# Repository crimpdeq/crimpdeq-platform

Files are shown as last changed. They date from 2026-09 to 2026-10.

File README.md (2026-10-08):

# Crimpdeq Platform

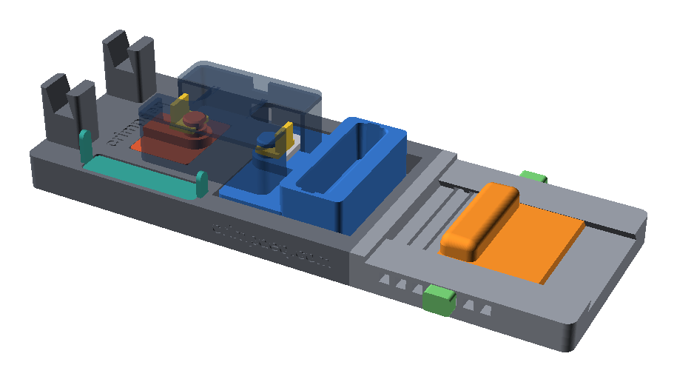
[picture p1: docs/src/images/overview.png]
Assembled platform


A parametric OpenSCAD platform that turns the [Crimpdeq](https://github.com/crimpdeq)
portable force sensor into an isometric finger dynamometer, printed
entirely in plastic with no hardware to buy.

## Specifications

- **Edge depths:** 25, 20, 15 and 10 mm, set with two stackable stoppers (5
  and 10 mm).
- **Palm rest:** 25–85 mm from the outside of the finger lip to the palm face,
  seven positions in 10 mm steps, with the heel level with the fingertips on
  the 20 and 25 mm edges.
- **Phone slot:** phones up to about 13 mm thick in their case, portrait or
  landscape, leaned back 15°.
- **Size:** 349 × 122 mm base (138 mm wide with the keys fitted), 60 mm tall
  at the phone stand.
- **Printing:** no supports and no hardware; the base splits into two halves
  for a 256 mm bed; about 640 g of PETG.
- **Compatibility:** [crimpdeq-case](https://github.com/crimpdeq/crimpdeq-case)
  v2.0.0 and earlier.

## Documentation

The [book](https://platform.crimpdeq.com) ([source](docs/src/SUMMARY.md)) covers the design requirements, a
step-by-step guide to printing and assembling the parts on a 256 mm printer,
and the development workflow. Build it locally with [mdBook](https://rust-lang.github.io/mdBook/):

```bash
mdbook serve docs
```

## Quick start

Ready-to-print STL files and a Bambu Studio project with the plates laid out
are attached to each
[release](https://github.com/crimpdeq/crimpdeq-platform/releases). To preview
the model or export the parts yourself:

```bash
openscad dynamometer_assembly.scad
bash export-parts.sh
```

Validate the geometry after any change to the model:

```bash
CHECK_JOBS=4 OPENSCAD_RENDER_FN=24 bash check-collisions.sh
```

## Safety

Never load the platform above its 49 kg rating, and pull only with both clips
and both keys fitted. Printed parts can fail: inspect them before each session
and stop using any part that cracks or deforms.

## License

This repository is source-available under the
[Crimpdeq Non-Commercial Hardware License](LICENSE). You may study, modify,
and build the design for personal, educational, and research use, and share
modified versions non-commercially. Commercial manufacture or sale of printed
parts, kits, or assembled devices requires prior written permission.
The bundled Inter font in `fonts/` is under its own
[SIL Open Font License](fonts/Inter-LICENSE.txt).

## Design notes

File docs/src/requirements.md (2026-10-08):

# Requirements

These are the requirements the design must keep. A change to the model that
breaks one is a design change, not a tweak, and this page changes with it.
The structural assertions and collision checks screen many of them; none of
them replaces testing printed parts.

## Load rating

- The platform is rated for 49 kg (about 481 N). The Crimpdeq itself is rated
  to 1500 N (about 150 kg); the printed lugs set the lower limit.
- The printed structure is sized with a 2.0 structural design factor, but the
  platform is never loaded above its 49 kg rating.

## Printing

- Every part is 3D-printed. There are no bolts, pins, inserts or other
  purchased hardware.
- Every part prints without supports.
- Each base half fits within the 240 mm printable length of a 256 mm bed
  (Bambu Lab A1). The halves join with vertical dovetails whose joint faces
  are in compression under load.

## Case and load path

- The platform holds the crimpdeq-case `v2.0.0` enclosure and every
  earlier release.
- The case lies flat, lid up, and floats at least 1 mm above the deck and
  clear of every printed part. Its shell, lid and screws never carry load.
- Hand force passes through printed round lugs in the Ø15 mm ring bores
  of both load-cell eyes: the anchor block's lug and the grip's lug. Each
  stands on a tongue rising through the case's eye U-slot, at least 1 mm
  from the case and its lid battery walls.
- The lugs are solid. The anchor block and grip print upright, so the lug and
  tongue roots are screened across the layers.
- Two snap-on eye clips hold the load cell down under the lug heads. Each
  fits by dropping into its U-slot and sliding onto the lug neck, with finger
  room beside the grip-side fin.
- The clips carry the grip's tilt but not the pull; the clip ring and lug
  neck are screened for that tilt.
- The switch and USB port stay reachable from the open +Y side of the base.

## Finger pocket and stoppers

- The four-finger hangboard pocket is exactly 25 mm deep, with an opening at
  least 80 mm wide, a 6 mm back wall and an 8 mm loading lip. Its +Z opening
  stays clear.
- The mid-depth of every edge is within 5 mm of the load-cell plane. The
  current model is at most 4 mm off, on the 10 mm edge.
- Two stackable drop-in stoppers, 5 and 10 mm thick, give 20, 15 and 10 mm
  edges. The closed pocket walls locate them.
- Their pull tabs run in slots in the pocket end walls and stand proud of the
  grip top, leaving the whole top of each stopper free for the fingers.
- The stoppers are stored in a well in the deck beside the case.
- Grip-guide ledges run under the grip's side walls with a 0.8–1.2 mm Z gap
  and free X travel, so they catch tilt without carrying measured load.

## Palm rest

- The heel deck (the rest's plate and the rear deck beside it) lies between
  the fingertips on the 20 and 25 mm edges (Z = −10 mm), so the heel and the
  fingers pull in line. The palm bolster rises 10–14 mm above it.
- Nothing but the bolster stands above the heel deck around the hand.
- The rest has seven positively locked positions, for hand openings of 25 to
  85 mm.
- The rest slides in a dovetail channel sunk into the rear base half, which
  carries the whole heel plate at every position. Two printed index keys,
  pushed in under the deck from the sides of the base, lock it. Adjustment
  needs no tools.
- Either index key alone is screened for the entire design force, and both
  travel extremes are checked after every geometry change.

## Phone stand

- A tilted phone slot runs across a two-cheek stand at the far (−X) end of
  the base. A narrow phone rests on both cheeks.
- The slot floor is at Z = 15 mm, so the case hides the phone only from
  viewpoints less than 20° above the table.
- The stand leaves finger room by the stopper well, is outside the load path,
  and is clear of the hand at every rest position.

## Clearances

- The base, anchor block, grip, clips, rest, keys, phone and case are
  collision-free except at explicitly modelled contact surfaces.

## Structural screening

`dynamometer_dimensions.scad` fails with an assertion when a parameter change
takes any of these checks past its limit. Values are at the 961 N design
target: the 481 N rating times the 2.0 design factor.

| Check | Stress | Limit |
|---|---|---|
| Eye bearing on each lug (14.3 mm × 4 mm) | 16.8 MPa | 20 MPa, lug bearing |
| Lug root bending across the layers, eye force at the load-cell mid-plane | 6.7 MPa | 12 MPa |
| Lug root shear across the layers | 5.98 MPa | 6 MPa |
| Tongue root at the deck, bending across the layers | 3.1 MPa | 12 MPa |
| Anchor block bearing on its pocket | 1.1 MPa | 12 MPa, bearing |
| Clip on the flat ring under the lug head, largest finger-pull tilt | 11.1 MPa | 12 MPa, bearing |
| Lug neck pulled by the clip, across the layers | 4.4 MPa | 12 MPa |
| Finger lip bending over the full 25 mm edge | 18.0 MPa | 30 MPa, bending |
| Grip side and back walls in tension | 1.2 MPa | 12 MPa |
| Either index key alone, in shear at the channel floor | 4.3 MPa | 12 MPa |
| Key bearing in the rest's groove / the floor groove | 10.4 / 7.4 MPa | 12 MPa, bearing |
| Rib between neighbouring floor grooves, in shear | 7.0 MPa | 12 MPa |
| Palm bolster root, across the layers | 1.1 MPa | 12 MPa |
| Channel lips holding the rest down | 0.8 MPa | 6 MPa |

The clip check takes the 10 mm edge's 4 mm offset, reacted between the clip
and the tongue seat 10 mm from the eye centre. The base joint is in
compression and is not screened; the stoppers, grip guides, stopper well and
phone stand are outside the load path.

The printed-material limits (`allowable_printed_*` and
`allowable_lug_bearing_mpa`) are assumptions that need coupon tests. The
calculations leave out the 3D stress field, notches, one-finger loading,
print defects, creep, fatigue and temperature, and they are not FEA or proof
tests. The design factor is not a demonstrated safety factor and never
permits loading the platform above 49 kg.

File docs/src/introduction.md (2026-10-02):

# Crimpdeq Platform

Assembled platform

Crimpdeq Platform is a parametric OpenSCAD design that turns the
[Crimpdeq](https://github.com/crimpdeq) force sensor into an isometric finger
dynamometer.

Every part is 3D-printed. There are no bolts, pins, inserts or other
hardware to buy.

## How this book is organised

[Requirements](requirements.md) lists what the design must keep.
[Build](build/index.md) explains how to print the parts and assemble them.
[Development](development/index.md) covers previewing, exporting, and
validating the model.

All illustrations are rendered from the project's OpenSCAD model, so they
match the exported parts.

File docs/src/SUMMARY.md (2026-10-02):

# Summary

[Introduction](introduction.md)

- [Requirements](requirements.md)
- [Build](build/index.md)
  - [Printing](build/printing.md)
  - [Assembly](build/assembly.md)
- [Development](development/index.md)

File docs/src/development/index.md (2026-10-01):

# Development

The model is plain OpenSCAD with no library dependencies:

- `dynamometer_dimensions.scad`: parameters and structural assertions.
- `dynamometer_parts.scad`: the printable parts.
- `dynamometer_assembly.scad`: preview and export entry point.
- `crimpdeq_reference.scad`: a simplified snapshot of the Crimpdeq case
  (crimpdeq-case v2.0.0) used for fit and collision checks.

All dimensions are in millimetres. Override parameters with `-D name=value`;
unsafe combinations fail with an assertion.

## Preview and export

```bash
openscad dynamometer_assembly.scad    # preview; options in Window → Customizer
bash export-parts.sh                  # every part as STL into exports/
python3 export-bambu-project.py       # Bambu Studio project into exports/
```

## Validate

Run after every geometry or dimension change:

```bash
CHECK_JOBS=4 OPENSCAD_RENDER_FN=24 bash check-collisions.sh
```

It checks the parts for collisions and required contacts, confirms that each
exported STL has the expected number of bodies, and that unsafe parameters
are rejected. `check-real-case.sh` runs the same fit checks against the real
[crimpdeq-case](https://github.com/crimpdeq/crimpdeq-case) source. CI runs
both on every pull request.

## Book

The images in `docs/src/images/` are rendered from the model; re-render them
after geometry changes and preview the book:

```bash
bash docs/illustrations/render-illustrations.sh
mdbook serve docs
```

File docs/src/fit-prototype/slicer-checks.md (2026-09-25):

# Slicer checks before printing

The checks take about 5 minutes per plate in Bambu Studio. Supports only
appear after slicing, so do them in **Preview**, not in Prepare.

## A. Set up the Preview view

1. Click **Slice plate**, then open **Preview**.
2. In the **Slicing Result** panel, set **Color Scheme** to **Line Type**.
   Brim, support, support interface and walls then get separate colours.
3. Click the vertical layer slider on the right once. **↑/↓** step one layer
   and **Shift+↑/↓** jump five.
4. Press **1** for top view and **0** for iso view. Right-drag pans; scroll zooms.

## B. Slicer warnings

- [ ] The bottom-right notification area shows no yellow or red warnings, such
  as *floating regions*, *empty layers* or *object outside plate*.

A floating-regions warning means something is missing support.

## C. Layer 1 (0.20 mm)

- [ ] Every tall part has a continuous **brim** ring around its outline.
- [ ] There's no brim inside the frame U openings, as expected with "Outer brim only".
- [ ] The brims of neighbouring parts are separate, or only just touch.
- [ ] The flat faces on the bed are fully filled.
- [ ] Support bases appear under the right-half channel bridge, the left-half
      clevis cheek, the wrist-rest deck and the grip cheek.
- [ ] Nothing reaches the plate edge or the purge/cutter zone at the back left.

## D. Plate 1: channel bridge (right half, about 14–18 mm)

Step up until the closed end of the right half starts spanning the channel.

- [ ] The layer just below has dense **support interface** under the bridge.
- [ ] The first bridge layer is straight parallel lines across the gap.
- [ ] The support trees stand on the plate, not on the brim or the other half.

## E. Plate 1: clevis cheek (left half, about 35–45 mm)

Step up until the cheek with the Ø17 hole first appears.

- [ ] Its first layer sits entirely on support interface, with no edge in free
      air, including the outer corner.
- [ ] The support trees don't lean against the other half.

## F. Plate 2: wrist rest and grip

- [ ] The first layer of the heel deck, roughly 35–50 mm up, sits on support
      interface with no free-hanging edge.
- [ ] The first layer of the grip's upper cheek sits on support interface.
- [ ] No support trees grow between the grip and the wrist rest.
- [ ] The top layer of the wrist rest is the palm surface, with no support on it.

## G. Peg bores, index holes and printed hardware

- [ ] The peg bores print as teardrops with a pointed top and no support inside.
- [ ] There's no support in the index holes.
- [ ] The bolts, pins, nuts and washers have no support.
- [ ] The two seam braces stand upright on their soles with no support.

## H. Top layer

- [ ] On Plate 1 the last layers are the feet, two on each half. They are
      complete.
- [ ] No stray support sticks up above any part.

## I. Printer and material

- [ ] The textured PEI plate matches the slicer's **Plate type**. Wash it with
      dish soap and warm water, dry it, and don't touch the surface.
- [ ] There's enough dry PLA on the spool for the plate, plus margin.
- [ ] There's nothing behind the printer for the moving bed to hit.
- [ ] **Bed leveling** is on in the print dialog.

## J. During the print

- **First 5 minutes:** brims and first layer are flat and stuck down. If a
  corner lifts, stop and clean or re-level.
- **Plate 1, about 16 mm:** the channel bridge lands on its support.
- **Plate 1, about 40 mm:** the clevis cheek lands on its support.
- **If any part comes loose, stop immediately.** On the A1 a loose tall part
  gets dragged into the others.

The heights above are approximate. Use the layer where each feature first
appears.

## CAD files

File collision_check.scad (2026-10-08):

// Standalone collision/fit probes for the all-printed Crimpdeq dynamometer.
// Seating faces are backed off 0.01 mm where contact is intended, so face
// contact is not reported as an overlap.

use <dynamometer_parts.scad>
use <crimpdeq_reference.scad>
include <dynamometer_dimensions.scad>

render_fn = is_undef(render_fn) ? 24 : render_fn;
$fn = render_fn;
mode = is_undef(mode) ? "anchor_case" : mode;
test_position = is_undef(test_position) ? 0 : test_position;
assert(test_position >= 0 && test_position < rest_index_count &&
    test_position == floor(test_position), "Invalid test index.");

module lifted(dz = 0.01) { translate([0, 0, dz]) children(); }

module fixed_parts() {
    base_front();
    base_rear();
    anchor_block();
}

module service_probe() {
    // Finger and cable room in front of the switch and USB openings.
    z_min = case_switch_z - case_switch_h / 2;
    z_max = case_usb_z + case_usb_h / 2 + 8;
    translate([-service_w / 2, case_y_max + 0.01, z_min])
        cube([service_w, service_y_max - case_y_max, z_max - z_min]);
}

module stopper_in_pocket(i, dx = 0, dy = 0, dz = 0) {
    translate([dx, dy, dz]) pocket_stopper(i);
}

if (mode == "anchor_case") {
    intersection() { anchor_block(); crimpdeq_case_reference(); }
} else if (mode == "grip_case") {
    intersection() {
        union() { finger_grip(); translate([rated_preview_deflection, 0, 0]) finger_grip(); }
        crimpdeq_case_reference();
    }
} else if (mode == "base_case") {
    // The case floats: even lowered by nearly its gap it clears the base.
    intersection() {
        union() { base_front(); base_rear(); }
        translate([0, 0, -case_float_gap + 0.1]) crimpdeq_case_reference();
    }
} else if (mode == "clips_case") {
    intersection() { eye_clips(); crimpdeq_case_reference(); }
} else if (mode == "case_drop") {
    // The case, with its load cell, lowers onto both lugs from above
    // without touching the tongues or lugs.
    intersection() {
        union() { anchor_block(); finger_grip(); }
        for (dz = [0.01, 1, 2, 3, 4, 5, 6, 8, 10, 12, 15, 20])
            translate([0, 0, dz]) {
                crimpdeq_case_reference();
                loadcell_reference();
            }
    }
} else if (mode == "anchor_base") {
    intersection() { lifted() anchor_block(); union() { base_front(); base_rear(); } }
} else if (mode == "anchor_seated") {
    intersection() { lifted(-0.02) anchor_block(); base_front(); }
} else if (mode == "anchor_bears") {
    // Pulled toward the grip, the anchor bears on the pocket's +X wall.
    intersection() {
        translate([anchor_play_x + 0.05, 0, 0.01]) anchor_block();
        base_front();
    }
} else if (mode == "grip_base") {
    intersection() {
        union() { finger_grip(); translate([rated_preview_deflection, 0, 0]) finger_grip(); }
        union() { fixed_parts(); }
    }
} else if (mode == "grip_guide_support") {
    // Dropped by just more than the guide gap, the grip lands on the ledge
    // of the selected side.
    assert(test_position < 2, "Guide index must be 0-1.");
    intersection() {
        translate([0, 0, -grip_guide_gap_z - 0.02]) finger_grip();
        base_front();
        translate([trench_x_min - 1, test_position == 0 ? -base_half_w_y : 0,
                   grip_guide_z_max - 1])
            cube([trench_x_max - trench_x_min + 2, base_half_w_y, 1.01]);
    }
} else if (mode == "tab_seated") {
    // The load cell rests on the anchor (0) and grip (1) seats.
    assert(test_position < 2, "Seat index must be 0-1.");
    intersection() {
        lifted(-0.02) loadcell_reference();
        if (test_position == 0) anchor_block(); else finger_grip();
    }
} else if (mode == "lug_clear") {
    // Both lugs pass through the eyes without touching the load cell.
    intersection() {
        lifted() loadcell_reference();
        union() { anchor_block(); finger_grip(); }
    }
} else if (mode == "lug_bearing") {
    // Pulling the grip (+X) brings each eye's outer rim onto its lug.
    assert(test_position < 2, "Lug index must be 0-1.");
    shift = lug_fit + 0.05;
    if (test_position == 0)
        intersection() { translate([shift, 0, 0.01]) loadcell_reference(); anchor_block(); }
    else
        intersection() { lifted() loadcell_reference(); translate([shift, 0, 0]) finger_grip(); }
} else if (mode == "clip_parts") {
    intersection() {
        lifted() eye_clips();
        union() { anchor_block(); finger_grip(); loadcell_reference(); }
    }
} else if (mode == "clip_clamp") {
    // Each clip presses on its end of the load cell.
    assert(test_position < 2, "Clip index must be 0-1.");
    intersection() {
        lifted(-0.02) eye_clip(test_position == 0 ? "left" : "right");
        loadcell_reference();
    }
} else if (mode == "clip_retained") {
    // Lifted (0-1), a clip catches its lug head; pulled outboard (2-3), its
    // fork snaps against the neck.
    assert(test_position < 4, "Clip index must be 0-3.");
    side = test_position % 2 == 0 ? "left" : "right";
    intersection() {
        if (test_position < 2)
            translate([0, 0, clip_head_gap + 0.05]) eye_clip(side);
        else
            lifted() eye_clip(side, dx = 1);
        if (side == "left") anchor_block(); else finger_grip();
    }
} else if (mode == "clip_path") {
    // Each clip drops into its U-slot beside the lug head, then slides in
    // over the load cell. Only the snap at the neck may touch on the way.
    assert(test_position < 2, "Clip index must be 0-1.");
    side = test_position == 0 ? "left" : "right";
    x_eye = test_position == 0 ? dyno_eye_x_left : dyno_eye_x_right;
    intersection() {
        union() {
            for (dz = [0.01, 2, 5, 10, 15, 20, 25])
                translate([0, 0, dz]) eye_clip(side, dx = clip_install_travel);
            for (dx = [0 : 1 : clip_install_travel])
                lifted() eye_clip(side, dx = dx);
        }
        difference() {
            union() {
                crimpdeq_case_reference(); anchor_block(); finger_grip();
                loadcell_reference();
            }
            translate([x_eye, dyno_eye_y, loadcell_top_z - 0.1])
                cylinder(r = lug_neck_r + 0.01, h = lug_head_z_min - loadcell_top_z + 0.1);
        }
    }
} else if (mode == "service_path") {
    intersection() {
        service_probe();
        union() {
            fixed_parts(); finger_grip(); eye_clips();
            palm_rest(-rest_adjust_range); index_keys(-rest_adjust_range);
            stored_pocket_stoppers();
        }
    }
} else if (mode == "base_halves_overlap") {
    intersection() { base_front(); translate([0.01, 0, 0.01]) base_rear(); }
} else if (mode == "base_joint_locked") {
    // Pulled apart, the rear half's sockets catch the dovetail tongues.
    intersection() { base_front(); translate([joint_catch_travel + 0.05, 0, 0.01]) base_rear(); }
} else if (mode == "base_joint_bears") {
    // Pushed together, the halves bear on their butt faces.
    intersection() { base_front(); translate([-0.02, 0, 0.01]) base_rear(); }
} else if (mode == "rest_position") {
    // The rest and both keys at each of the seven positions.
    o = rest_offset(test_position);
    intersection() {
        lifted() palm_rest(o);
        union() { fixed_parts(); finger_grip(); eye_clips(); crimpdeq_case_reference(); }
    }
    intersection() {
        lifted() index_keys(o);
        union() { fixed_parts(); palm_rest(o); finger_grip(); }
    }
} else if (mode == "rest_locked") {
    // At both travel ends, each key catches its floor groove and the plate's
    // groove in X.
    assert(test_position < 4, "Lock index must be 0-3.");
    o = test_position < 2 ? -rest_adjust_range : rest_adjust_range;
    shift = (test_position % 2 == 0 ? -1 : 1) * (key_fit / 2 + 0.05);
    intersection() { translate([shift, 0, 0.02]) index_keys(o); base_rear(); }
    intersection() { translate([shift, 0, 0.02]) index_keys(o); palm_rest(o); }
} else if (mode == "rest_retained") {
    // Lifted off the channel floor at its least-engaged position, the
    // plate's flanks catch the channel's lips.
    intersection() {
        translate([0, 0, rest_catch_travel + 0.05]) palm_rest(rest_adjust_range);
        base_rear();
    }
} else if (mode == "rest_slide_on") {
    // Without keys, the rest slides on from the rear end to its first position.
    start = base_x_max + 1 - rest_face_x(0);
    steps = ceil((start + rest_adjust_range) / rest_index_pitch);
    intersection() {
        union() { fixed_parts(); finger_grip(); }
        for (i = [0 : steps])
            lifted() palm_rest(max(-rest_adjust_range, start - i * rest_index_pitch));
    }
} else if (mode == "finger_entry") {
    // Minimum drafted pocket envelope and its unobstructed +Z approach.
    intersection() {
        dyno_rounded_prism_xy(
            hangboard_opening_x_min + hangboard_draft + 0.01,
            hangboard_opening_x_max - hangboard_draft - 0.01,
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

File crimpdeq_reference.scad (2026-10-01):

//
// Self-contained Crimpdeq v2 (crimpdeq-case v2.0.0) interface reference.
// This is a fit/collision model, not a replacement for crimpdeq-case.
//

include <dynamometer_dimensions.scad>

render_fn = is_undef(render_fn) ? 96 : render_fn;
$fn = render_fn;

case_inner_corner_r = case_corner_r - case_wall_t;

module ref_rounded_rect_2d(x_min, x_max, y_min, y_max, r) {
    w = x_max - x_min;
    h = y_max - y_min;
    rr = max(0, min(r, min(w, h) / 2 - 0.01));

    if (rr > 0)
        translate([x_min + rr, y_min + rr])
            offset(r = rr)
                square([w - 2 * rr, h - 2 * rr], center = false);
    else
        translate([x_min, y_min])
            square([w, h], center = false);
}

module ref_rounded_prism(x_min, x_max, y_min, y_max, z_min, z_max, r) {
    translate([0, 0, z_min])
        linear_extrude(height = z_max - z_min)
            ref_rounded_rect_2d(x_min, x_max, y_min, y_max, r);
}

module loadcell_2d_reference() {
    // Each eye with its pressed-in ring, which crimpdeq-case does not model.
    difference() {
        square([lc_L, lc_W], center = true);
        for (x_pos = [dyno_eye_x_left, dyno_eye_x_right])
            translate([x_pos, 0])
                circle(d = eye_bore_d);
    }
}

module loadcell_reference() {
    color("silver")
        translate([0, 0, loadcell_bottom_z])
            linear_extrude(height = lc_T)
                loadcell_2d_reference();
}

module case_eye_u_slots_reference() {
    // A vertical U-slot round each eye, open to the case end, through the
    // full height of the case and lid.
    for (side = [-1, 1])
        translate([0, 0, case_z_min - 0.2])
            linear_extrude(height = case_z_max - case_z_min + 0.4)
                union() {
                    translate([side * dyno_eye_x_right, dyno_eye_y])
                        circle(d = case_eye_u_d);
                    translate([side > 0 ? dyno_eye_x_right : -case_x_half - 0.2,
                               dyno_eye_y - case_eye_u_d / 2])
                        square([case_x_half + 0.2 - dyno_eye_x_right, case_eye_u_d]);
                }
}

module case_service_openings_reference() {
    translate([case_switch_x, case_y_max, case_switch_z])
        cube([case_switch_w + 0.8, 2 * case_wall_t + 0.4, case_switch_h + 0.8], center = true);
    translate([case_usb_x, case_y_max, case_usb_z])
        cube([case_usb_w, 2 * case_wall_t + 0.4, case_usb_h], center = true);
}

module crimpdeq_main_reference() {
    difference() {
        ref_rounded_prism(-case_x_half, case_x_half, case_y_min, case_y_max,
            case_z_min, case_lid_z, case_corner_r);
        ref_rounded_prism(-case_x_half + case_wall_t, case_x_half - case_wall_t,
            case_y_min + case_wall_t, case_y_max - case_wall_t,
            case_z_min + case_wall_t, case_lid_z + 0.2, case_inner_corner_r);
        case_eye_u_slots_reference();
        case_service_openings_reference();
    }
}

module lid_battery_walls_reference() {
    // Walls into the inboard edge of each U-slot, and the lid bridges that
    // join them to it at the top.
    for (side = [-1, 1]) {
        translate([side * case_battery_wall_x, 0,
                   (case_battery_wall_z_min + case_z_max) / 2])
            cube([case_battery_wall_t, case_battery_wall_l_y,
                  case_z_max - case_battery_wall_z_min], center = true);
        translate([side * (case_u_bridge_x_min + case_battery_wall_x) / 2, 0,
                   (case_lid_z + case_z_max) / 2])
            cube([case_battery_wall_x - case_u_bridge_x_min, case_battery_wall_l_y,
                  case_z_max - case_lid_z], center = true);
    }
}

module crimpdeq_lid_reference() {
    union() {
        difference() {
            ref_rounded_prism(-case_x_half, case_x_half, case_y_min, case_y_max,
                case_lid_z, case_z_max, case_corner_r);
            case_eye_u_slots_reference();
        }
        lid_battery_walls_reference();
    }
}

module crimpdeq_case_reference() {
    union() {
        crimpdeq_main_reference();
        crimpdeq_lid_reference();
    }
}

module crimpdeq_internals_reference() {
    loadcell_reference();

    // Battery, PCB and switch envelopes.
    color([0.1, 0.45, 0.8, 0.7])
        translate([0, -7.5, 11.5])
            cube([34, 50, 10], center = true);
    color([0.1, 0.55, 0.2, 0.8])
        translate([0, 1.8, 20])
            cube([23, 63.8, 5], center = true);
    color([0.7, 0.1, 0.1, 0.8])
        translate([case_switch_x, 27, case_switch_z])
            cube([15, 13, 10], center = true);
}

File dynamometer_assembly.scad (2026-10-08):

//
// All-printed Crimpdeq finger dynamometer: preview and STL export entry point.
//
// Examples:
//   openscad dynamometer_assembly.scad
//   openscad -D 'part="base_front"' -o /tmp/dyno-base-front.stl dynamometer_assembly.scad
//   openscad -D 'part="grip"' -D on_plate=true -o /tmp/dyno-grip.stl dynamometer_assembly.scad
//
// Parts: base_front, base_rear, anchor, grip, clips, keys, rest, stoppers.
// The view options below are literals so that OpenSCAD's Customizer
// (Window > Customizer) lists them; -D still overrides them.
//

use <dynamometer_parts.scad>
use <crimpdeq_reference.scad>
include <dynamometer_dimensions.scad>

/* [View] */
// Part to preview or export
part = "assembly"; // [assembly, base_front, base_rear, anchor, grip, clips, keys, rest, stoppers]
// Preview pose; rated exaggerates the grip displacement
pose = "unloaded"; // [unloaded, rated, exploded]
// Export the part at its place on the print plate instead of the origin
on_plate = false;
// Palm rest position, from the smallest (-1) to the largest (1) opening
rest_position = 0; // [-1:0.25:1]

/* [Show] */
show_case = true;
show_internals = true;
show_rest = true;
// Pocket stoppers; any not in the pocket stay in their storage well
show_stoppers = true;
// Stoppers fitted in the finger pocket, by thickness in mm
pocket_stoppers = "none"; // [none, 5, 10, both]
// Largest supported phone in its slot
show_phone = false;

/* [Hidden] */
render_fn = is_undef(render_fn) ? 96 : render_fn;
$fn = render_fn;

grip_preview_offset = pose == "rated" ? rated_preview_deflection : 0;
explode = pose == "exploded" ? 1 : 0;
rest_x_offset = round(rest_position * rest_adjust_range / rest_index_pitch) * rest_index_pitch;

assert(pose == "unloaded" || pose == "rated" || pose == "exploded",
    str("Unknown pose: ", pose));
assert(rest_position >= -1 && rest_position <= 1,
    "rest_position must be between -1 and +1.");

// Stopper indices in the pocket (bottom first) and in the storage well.
stoppers_in_pocket = [for (i = [0 : stopper_count - 1])
    // The Customizer passes 5 and 10 as numbers; -D may pass strings.
    if (pocket_stoppers == "both" || str(stopper_t_list[i]) == str(pocket_stoppers)) i];
stoppers_stored = [for (i = [0 : stopper_count - 1])
    if (len(search(i, stoppers_in_pocket)) == 0) i];
assert(pocket_stoppers == "none" || len(stoppers_in_pocket) > 0,
    str("Unknown pocket_stoppers: ", pocket_stoppers));

module stopper_stack(indices) {
    // The listed stoppers stacked from the pocket floor datum, in order.
    if (len(indices) > 0)
        for (k = [0 : len(indices) - 1])
            translate([0, 0, k == 0 ? 0 : stopper_t_list[indices[0]]])
                pocket_stopper(indices[k]);
}

module dynamometer_complete() {
    color([0.40, 0.42, 0.46]) base_front();
    color([0.58, 0.60, 0.64]) translate([30 * explode, 0, 0]) base_rear();
    color([0.85, 0.35, 0.20]) translate([0, 0, 30 * explode]) anchor_block();
    color([0.20, 0.45, 0.78]) translate([grip_preview_offset, 0, 30 * explode]) finger_grip();
    color([0.95, 0.80, 0.25]) translate([0, 0, 90 * explode]) eye_clips();

    if (show_case)
        translate([grip_preview_offset / 2, 0, 60 * explode]) {
            color([0.12, 0.18, 0.25, 0.9]) crimpdeq_main_reference();
            color([0.18, 0.28, 0.38, 0.85]) crimpdeq_lid_reference();
            if (show_internals) %crimpdeq_internals_reference();
        }

    if (show_rest)
        translate([30 * explode, 0, 30 * explode]) {
            color([0.95, 0.55, 0.15]) palm_rest(rest_x_offset);
            color([0.45, 0.80, 0.45])
                index_keys(rest_x_offset, 30 * explode);
        }

    if (show_phone)
        color([0.1, 0.1, 0.1, 0.6]) phone_reference();

    if (show_stoppers)
        color([0.2, 0.6, 0.55]) {
            translate([grip_preview_offset, 0, 60 * explode])
                stopper_stack(stoppers_in_pocket);
            stopper_well_transform() stopper_stack(stoppers_stored);
        }
}

if (part == "assembly") {
    dynamometer_complete();
} else if (on_plate) {
    print_plate_placement(part) print_layout(part);
} else {
    print_layout(part);
}

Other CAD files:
dynamometer_dimensions.scad
docs/illustrations/illustrations.scad
dynamometer_parts.scad

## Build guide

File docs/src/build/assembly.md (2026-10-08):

# Assembly

## 1. Join the base halves

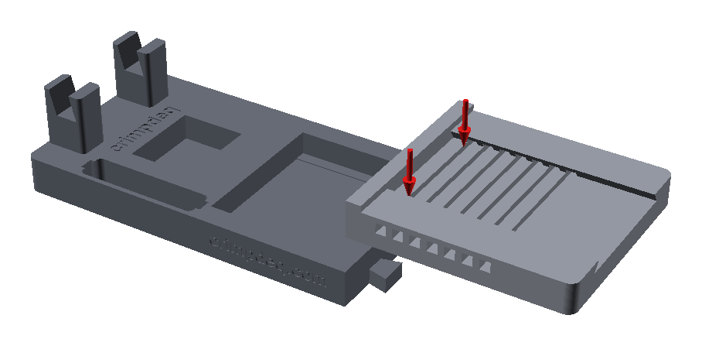
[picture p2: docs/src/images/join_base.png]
Lowering the rear half onto the front half


Lower the rear half straight down onto the front half's two dovetail
tongues until both halves stand flat on the table.

## 2. Fit the anchor block

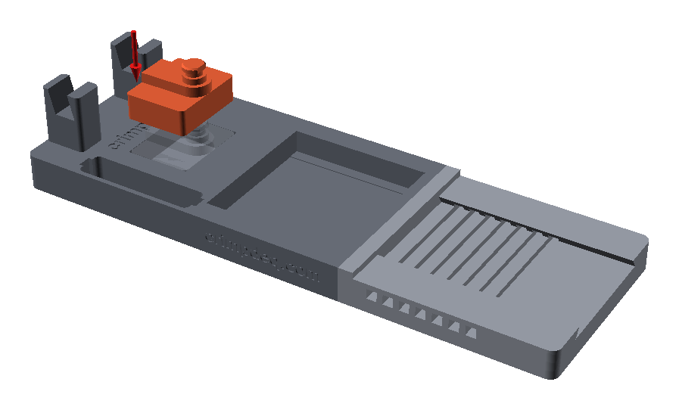
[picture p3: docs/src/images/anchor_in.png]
Dropping the anchor block into its pocket


Drop the anchor block into its pocket at the outer end of the front half,
lug toward the middle.

## 3. Fit the grip and the case

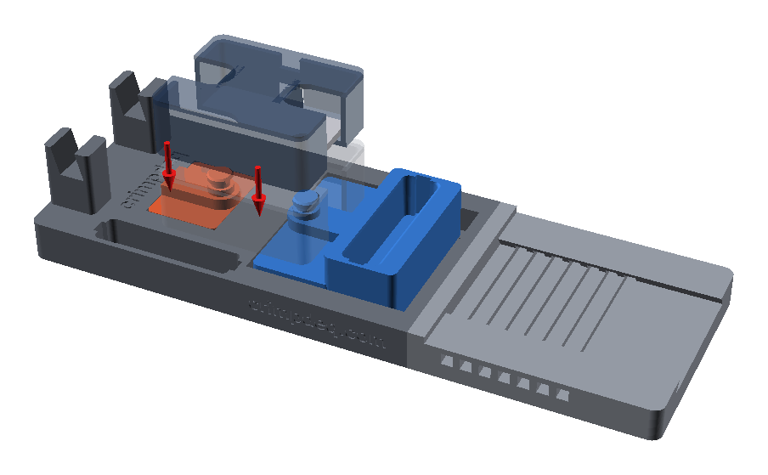
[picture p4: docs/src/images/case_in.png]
Lowering the case onto the lugs


1. Drop the grip into its trench, lug toward the anchor block.
2. Hold the Crimpdeq case lid up, with the switch and USB port facing the
   open side of the base.
3. Lower it so the anchor block's lug enters the load-cell eye at the left
   end. Slide the grip until its lug lines up with the right end, then let
   the case down.

The case must not touch the deck or any printed part; only the load cell
rests on the lugs.

The grip must hang free on the load cell: a strip of paper slides between
each guide ledge and the grip's side walls. If the grip rests on a ledge,
friction there takes part of the pull and the Crimpdeq reads low.

## 4. Fit the clips

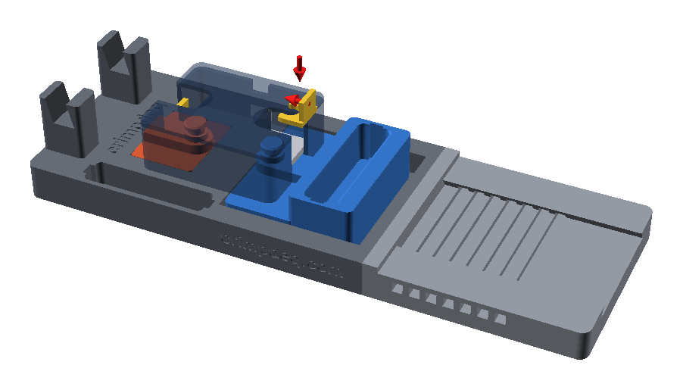
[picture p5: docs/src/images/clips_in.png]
Fitting the clips


For each lug, drop a clip flat into the slot in the case end beside the lug,
then push it in by its fin until it snaps round the lug's neck.

To remove the case, pull both clips out by their fins and lift it straight
up.

## 5. Fit the palm rest

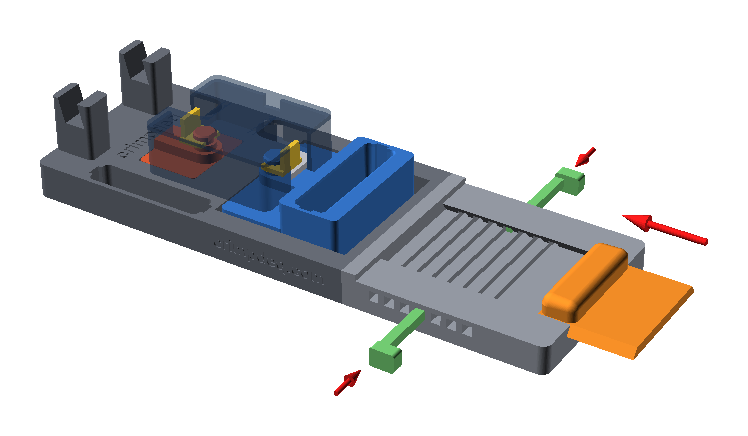
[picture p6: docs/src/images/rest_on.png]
Sliding the palm rest onto the rail


Slide the palm rest into the channel from the rear end, bolster toward the
grip. Push one key into the side of the base from each side, through the
groove under the bolster, until its head meets the base.

The seven key holes along each side, counted from the grip, set the opening
between the finger lip and the palm face: 25 to 85 mm in 10 mm steps. To
change it, pull both keys out by their heads, slide the rest until its groove
lines up with the new holes, and push them in again.

## 6. Stoppers and phone

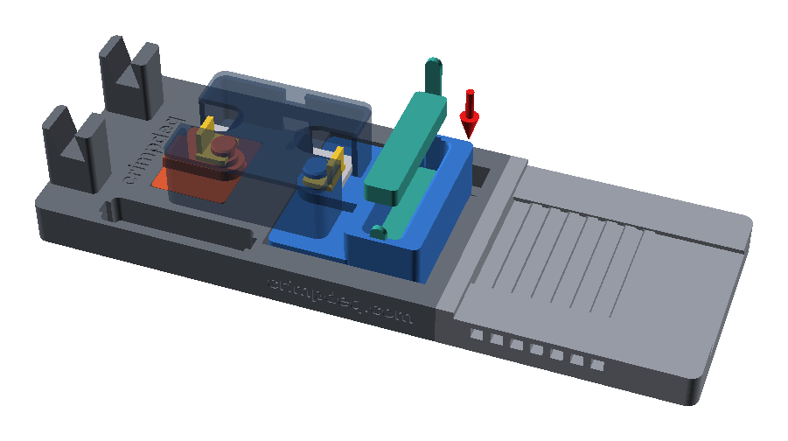
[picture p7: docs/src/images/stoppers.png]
Fitting the stoppers


The pocket gives a 25 mm edge on its own. Drop a stopper onto its floor, pull
tab in the end slot, for a shallower edge:

| Edge | Stoppers |
|---|---|
| 25 mm | none |
| 20 mm | 5 mm |
| 15 mm | 10 mm |
| 10 mm | both, tabs at opposite ends |

Store unused stoppers in the well beside the case.

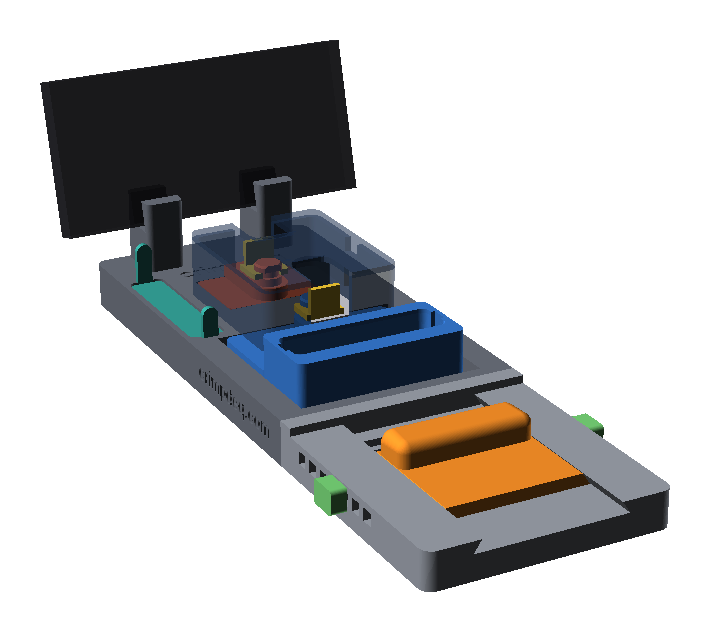
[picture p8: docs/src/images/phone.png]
Phone in its slot


Stand your phone in the slot at the far end of the base, in portrait or
landscape. It takes phones up to about 13 mm thick in their case.

Tare the Crimpdeq unloaded before measuring.

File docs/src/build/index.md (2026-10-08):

# Build

Assembled platform

The platform prints on a Bambu Lab A1, or any printer with a 256 mm bed, in
about 640 g of PETG. There is nothing else to buy. It holds the Crimpdeq case
from [crimpdeq-case v2.0.0](https://github.com/crimpdeq/crimpdeq-case/tree/v2.0.0)
or any earlier release.

> [!WARNING]
> Never load the platform above its 49 kg rating, and pull only with both
> clips and both keys fitted. Printed parts can fail: inspect them before each
> session and stop using any part that cracks or deforms.

## Parts

The illustrations use the same colours throughout:

- **Base** (grey), printed as a front and a rear half.
- **Anchor block** (red) and **finger grip** (blue): their lugs go into the
  two eyes of the load cell.
- **Eye clips** (yellow): hold the load cell down on the lugs.
- **Palm rest** (orange) and **index keys** (green): set the hand opening.
- **Pocket stoppers** (teal): make the 25 mm edge shallower.

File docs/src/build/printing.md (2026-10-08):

# Printing

## Files

Each [release](https://github.com/crimpdeq/crimpdeq-platform/releases)
includes the STL files and `crimpdeq-platform.3mf`, a Bambu Studio project
with both plates laid out and the settings below applied. The project is set
up for a Bambu Lab A1 with a 0.4 mm nozzle, Generic PETG and the textured PEI
plate. Open it with **File → Open Project**, select your printer, filament
and plate, and print.

Take all the parts from the same release, or they may not fit together.

## Plates

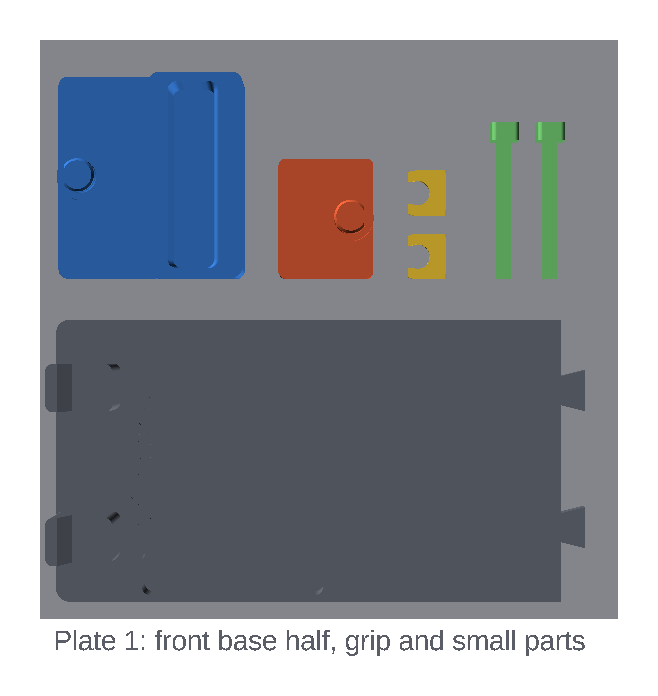
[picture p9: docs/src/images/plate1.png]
Plate 1: front base half, grip, anchor block, clips and keys


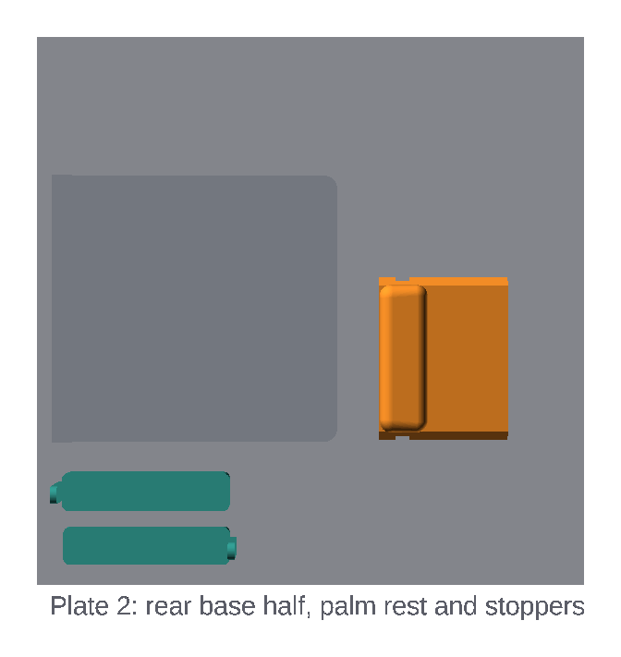
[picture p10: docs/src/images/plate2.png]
Plate 2: rear base half, palm rest and stoppers


The parts are exported already oriented for printing, so don't rotate them.
If you lay out the plates yourself, keep the parts at least 15 mm apart.

## Print settings

| Setting | Value |
|---|---|
| Layer height | 0.2 mm |
| Walls | 6 |
| Top/bottom layers | 6 |
| Infill | 20% |
| Supports | **Off** |
| Brim | Outer brim only, 5 mm |

Per-object overrides:

| Object | Override |
|---|---|
| `grip`, `anchor`, `clips`, `keys` | 100% infill |
| `rest` | 50% infill |
| `base_front`, `base_rear` | 4 top and 4 bottom layers |

To save filament, the project also prints these lightly loaded zones
sparser, using height range modifiers:

| Object | Range | Infill |
|---|---|---|
| `base_front` | 22.6–59.6 mm | 10% |
| `rest` | 6–18 mm | 15% |
| `anchor` | 0–11.5 mm | 40% |

No part needs supports. Keep them off: they would scar the faces that the
load-cell eyes and the palm rest bear on.

After printing, remove the brims and trim any flared first layer on the base
halves' joint faces and on the palm rest's sole.

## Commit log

2026-09-25 feat: add Crimpdeq hand dynamometer platform
    [collision_check.scad, crimpdeq_reference.scad, dynamometer_assembly.scad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]
2026-09-25 ci: add checks and STL release workflow
2026-09-25 docs: render illustrations with transparent backgrounds
    [illustrations.scad]
2026-09-25 docs: show split frame and seam braces in illustrations
    [illustrations.scad]
2026-09-25 docs: remove prototype caution and credits
2026-09-25 feat: bolt frame halves and drop test-only parts
    [collision_check.scad, dynamometer_assembly.scad, dynamometer_dimensions.scad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]
2026-09-25 docs: replace fit prototype guide with bolted build guide
    [illustrations.scad]
2026-09-25 fix: let frame lap screws reach nuts at the pocket mouth
    [dynamometer_dimensions.scad]
2026-09-25 docs: re-render frame illustrations for deeper screw counterbores
2026-09-26 test: ignore seating-face contact in frame joint hardware probe
    [collision_check.scad]
2026-09-26 fix: run collision checks on macOS bash and current OpenSCAD
    [collision_check.scad]
2026-09-26 feat: widen grip, raise wrist rest, add stoppers and phone slot
    - Widen the finger pocket to 80 mm and deepen it to 25 mm; the frame now
    follows the grip width (#3).
    - Add grip-guide ledges on the rail inner faces under the grip side walls,
    with a 0.3 mm Z gap and free X travel, to stop the grip tilting (#2).
    - Raise the heel deck 20 mm so it sits above the pin heads and passes over
    a solid right post; drop the post channel (#4).
    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
    [collision_check.scad, dynamometer_assembly.scad, dynamometer_dimensions.scad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]
2026-09-26 ci: require the stoppers STL in releases
2026-09-26 docs: document stoppers, phone slot, grip guides and raised rest
    Update the design chapter and build guide for the 80 x 25 mm pocket, grip
    guides, raised heel deck, pocket stoppers and phone slot. The wider frame
    halves now print on separate plates. Add a stoppers-and-phone build page,
    re-render every illustration, and let the render script run on macOS bash.
    [illustrations.scad]
2026-09-26 fix: raise only the palm bolster, keep the heel deck level
    Return the heel deck to the pocket mouth (Z 34) and restore the right-post
    channel it slides through. The palm bolster now rises 32 mm instead of
    12 mm, so its top stays at Z 66, 14.5 mm above the pin buttons. Add a
    bolster bending screen and a pin-clearance assertion, and update the docs
    and illustrations.
    [dynamometer_dimensions.scad, dynamometer_parts.scad]
2026-09-26 fix: lower the palm bolster to 20 mm above the deck
    The 32 mm bolster was too high. Its top is now at Z 54, 20 mm above the
    frame top and 2.5 mm above the pin buttons; the pin-clearance assertion
    now requires at least 2 mm.
    [dynamometer_dimensions.scad]
2026-09-26 feat: replace the three stoppers with two stackable ones
    Drop the 15 mm stopper: the 5 and 10 mm stoppers now stack, in either
    order, for the 10 mm edge. Each has its own knotted pull holes on one side
    of the centre line and clearance holes for the other's cords. The storage
    well is 16 mm deep. Add probes for both stacking orders and the cord path,
    and update the docs and illustrations.
    [collision_check.scad, dynamometer_dimensions.scad, dynamometer_parts.scad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]
2026-09-26 feat: lift the stoppers by built-in pull tabs instead of cords
    Each stopper gets a 4 x 8 mm tab at one end, outside the finger width,
    standing 6 mm above the grip top so it can be pinched and pulled out. The
    10 mm stopper is notched for the 5 mm stopper's tab, so they stack with the
    5 mm one at the bottom. Drop the cord holes, the cord and the cord-path
    probes; add tab probes, and update the docs and illustrations.
    [collision_check.scad, dynamometer_dimensions.scad, dynamometer_parts.scad]
2026-09-26 fix: move the stopper tabs into slots in the pocket end walls
    The tabs stood inside the stopper ends and narrowed the edge to 69.5 mm
    when stacked. They now sit on the stopper end faces and run in vertical
    slots in the pocket end walls, leaving the whole 77.5 mm stopper top free
    for the fingers and 2 mm of wall behind each slot. The stoppers no longer
    need a notch and stack in either order again. Add a probe that nothing
    stands above either plate, and update the docs and illustrations.
    [collision_check.scad, dynamometer_dimensions.scad, dynamometer_parts.scad]
2026-09-27 feat: list the preview options in the OpenSCAD Customizer
    Turn the view options in dynamometer_assembly.scad into annotated literals,
    grouped into View and Show tabs with lists for the part and pose, a slider
    for the wrist position and checkboxes for the rest. -D still overrides
    them, so the scripts are unchanged.
    [dynamometer_assembly.scad]
2026-09-27 feat: add a pocket_stoppers preview option
    Fit the 5 mm stopper, the 10 mm stopper, or both stacked in the finger pocket from the Customizer or -D; the others stay in the storage well. Stoppers in the pocket move with the grip in the rated an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
    [dynamometer_assembly.scad]
2026-09-27 fix: accept numeric pocket_stoppers values from the Customizer
    [dynamometer_assembly.scad]
2026-09-27 docs: correct the clevis hole and add wrist-arm sanding
2026-09-27 chore: refresh stale pocket, bolster and print comments
    [collision_check.scad, dynamometer_parts.scad]
2026-09-27 fix: model the full M8 bolt and DIN 985 nyloc nut
    [dynamometer_dimensions.scad, dynamometer_parts.scad, illustrations.scad]
2026-09-27 test: require the stoppers STL to export as two bodies
2026-09-27 docs: re-render the M8 joint sections for the DIN 985 nut
2026-09-28 docs: explain why the frame halves print on separate plates
2026-09-28 Publish a ready-to-print Bambu Studio project (#17)
    * feat: publish a ready-to-print Bambu Studio project with each release
    * fix: keep Bambu Studio plate names by avoiding colons
    * fix: render Bambu Studio plate thumbnails in CI under Weston
    * fix: give Bambu Studio's GLEW an OSMesa context in CI
    * fix: build the Bambu Studio project on macOS so it has thumbnails
    * fix: build the Bambu Studio project on an Intel macOS runner
    * fix: build the Bambu Studio project on Linux without thumbnails
    [dynamometer_assembly.scad, dynamometer_dimensions.scad, dynamometer_parts.scad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]
2026-10-01 Redesign the platform as an all-printed dynamometer (#19)
    * feat: redesign the platform as an all-printed dynamometer
    The Crimpdeq case now lies flat on a printed base and floats clear of it. Printed D-shaped lugs on a side-printed anchor block and finger grip sit in the exposed outer halves of the load-cell eyes of the compact case, and slide-in keepers clamp the load-cell ends. A palm rest on a dovetail rail locks into nine 25-105 mm openings with two printed keys, and the two-piece base drops together on printed dovetails. No bolts, pins, inserts or other hardware remain.
    The case reference, structural screens, collision probes, real-case check, exports, Bambu Studio project, book and i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
    [collision_check.scad, crimpdeq_reference.scad, dynamometer_assembly.scad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]
2026-10-02 Prepare the docs for the public release (#23)
    * docs: restore the requirements as a top-level book page
    * docs: drop the unused section and rest position illustrations
    * docs: add a safety note and a limitation of liability
    * docs: check that the grip hangs free before measuring
    * docs: restore the structural screening table in the requirements
    [illustrations.scad]
2026-10-06 test: keep the pulled clip_retained probe off the load cell face (#26)
    [collision_check.scad]
2026-10-08 Lower the palm rest's heel to fingertip height (#24)
    * feat: lower the palm rest's heel to fingertip height
    Sink the palm rest into a dovetail channel in the rear base half so the heel
    deck sits at Z -10 mm, between the fingertips on the 20 and 25 mm edges, and
    the heel and fingers pull in line. The rear half lengthens to carry the whole
    heel plate at every position, and the base joint tongues stop under the
    channel floor.
    Replace the top-entry keys and wings with two bars pushed in from the base's
    sides, under the deck, so nothing but the bolster stands near the hand.
    * docs: describe the lowered palm rest and side keys
    * fix: reject overrides that cut the rest channel or disengage the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
    [collision_check.scad, dynamometer_assembly.scad, dynamometer_dimensions.scad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]
2026-10-19 Release v0.5.0 (#37)
    * feat: lock the palm rest with one full-width index key (#27)
    A single bar across the base replaces the two half-width keys. It engages the rest's plate over 76 mm instead of 37 mm per key, halving the key stresses, loads the plate symmetrically, and needs one push from either side. The key moves to plate 2, where its 130 mm length fits.
    * refactor: move the model to platform/ and tooling to scripts/ (#28)
    * docs: reduce requirements to outcomes and set a 45 kg minimum rating (#29)
    * docs: relax the hardware and support printing requirements
    * docs: apply the print bed requirement to every part
    * docs: reduce requirements to outcomes, not mechanisms
    Drop mechanis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
2026-10-19 feat: fit crimpdeq-case v3.1.0 alongside v2.0.0 (#38)
    The v3 case is hexagonal with a point at each end, and each eye's U-slot
    has an inboard flat over the eye's bore through the full case height. The
    tongues and lugs are now cut flat inboard through their full height so the
    case lowers past them. The collision probes clear the v2 and v3 references
    at once, and the anchor end of the base grows 4.7 mm for v3's longer ends.
    The flat takes area from the lug root, so its cross-layer shear screen,
    now computed on the flatted section, limits the rating to 46 kg (was
    49 kg). The real-case check aligns each release's load cell with the
    platform's, and CI runs it against both releases.
2026-11-10 feat: fit crimpdeq-case v3.2.0 (#39)
    Add a v3.2.0 snapshot to the case reference: v3.1.0's plan with 67-degree
    facets and a lower lid, top and USB opening. Its corners lie outside the
    v3.1.0 snapshot, so it needs its own.
    Lower the clip fins from 20 to 17 mm to keep them 4 mm below the lowest
    case top, and run the real-case CI check against v3.2.0.
2026-11-11 feat: print the palm rest's bolster with fuzzy skin (#40)
    * feat: groove the palm rest's bolster for grip
    Cut eleven 0.6 mm round-bottomed grooves along the bolster, 3 mm apart
    over its front round, top and rear round, so the palm does not slide over
    it. They stop before the bolster's rounded ends and only remove material,
    so clearances and fits are unchanged.
    * feat: print the palm rest's bolster with fuzzy skin
    Replace the bolster's grooves with a sandpaper-like fuzzy skin on its outer
    walls, set in the Bambu project's existing bolster height range so the heel
    plate's flanks stay smooth to slide in their channel. The model is back to
    main's geometry.
2026-11-12 fix: hold the anchor down and load the lugs within their layers (#41)
    * fix: hold the anchor down and load the lugs within their layers
    Address the model review:
    - Hold the anchor block down with a tapered printed key under the deck.
    The pull tipped the anchor, load cell and grip onto the guide ledges,
    whose friction made the Crimpdeq read low. Screen the key, the block
    round its tunnel and the resulting tilt, with a tilt collision probe.
    - Print the grip and the anchor block on their sides, so the lug, tongue
    and lip roots carry the pull within the layers. Widen the keel to the
    body and flatten the lugs where their supports touch. Screen the lug
    root with its peak shear and vo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
2026-11-12 perf: print the base halves with adaptive cubic infill (#42)
